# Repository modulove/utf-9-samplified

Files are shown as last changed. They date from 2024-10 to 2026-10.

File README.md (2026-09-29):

# UTF-9-samplified Drum Computer  

This project is based on the [bleep drum](https://bleeplabs.com/product/the-bleep-drum/) design by Dr. Bleep.

In 2025, **Felix Wiegeand (wgdmodular)** picked it up and released this **utf-9-samplified drum machine clone** with nice upgrades that make it perfect for starters and pros.

We (Modulove) put these into the hands of **beginners at DIY synthesizer solder workshops in 2025**.

- Few dozens were built.
- Every single one worked :)
- All were **hand-soldered by beginners (even kids!)**.

It turned out to be a **perfect entry-level project**.

The new firmware adds **Additonal functionality, fixes, and performance tricks** that came out of those builds and feedback from users.

---

## Firmware Updates

**Stable firmware (recommended):** 
Fixes the **button confusion issue**, fixed bad button behavior, small optimizations.
[https://dl.modulove.de/module/utf9/](https://dl.modulove.de/module/utf9/)

**Beta firmware (optional):**
Adds the new features: save/load slots, MIDI-to-CV clock, and more.
[https://dl.modulove.de/module/utf9/beta.html](https://dl.modulove.de/module/utf9/beta.html) 

Flash tool & instructions: [https://dl.modulove.de/module/utf9/](https://dl.modulove.de/module/utf9/)

---

## Supported boards

The firmware builds from a single sketch for three targets:

| Board | Notes |
|---|---|
| Arduino Nano | ATmega328P, new bootloader (115200 baud) |
| Arduino Nano (Old Bootloader) | ATmega328P, 57600 baud |
| LGT8F328P | Nano clone, built at `clock_div=2` so the chip runs at 16 MHz |

The LGT8F328P is an AVR-compatible clone whose internal RC oscillator runs at
32 MHz. The build divides it to 16 MHz so every timing in the sketch matches
the Nano, and the sample clock is derived from `F_CPU` rather than hardcoded,
so it lands on 9803.9 Hz on both. The LGT8F has no real EEPROM - the core
emulates it in flash, where writing one byte erases and rewrites a 1 KB page -
so pattern saves are staged and written as a single burst there.

None of this costs the Nano anything: the ATmega builds are byte-for-byte the
same size as before the dual-platform change.

**The Standard drumkit is Nano-only.** The LGT8F bootloader reserves 3 KB,
leaving 29696 bytes against the Nano's 30720, and Standard's sample set builds
to 30658. The other five kits all fit.

---

## Documentation

Docs of the **new features** here:

[docs/README.md](./docs/README.md)

The BOM is the docs/ folder as well.
[docs/BOM.md](./docs/BOM.md)

Find the ibom here:
[https://dl.modulove.de/module/utf9/ibom.html](https://dl.modulove.de/module/utf9/ibom.html)

---

## Links

The original Bleep Drum 
[https://bleeplabs.com/product/the-bleep-drum/](https://bleeplabs.com/product/the-bleep-drum/).

Old Bleep Drum User Guide & Hacking Info
[https://bleeplabs.com/bleep-drum-user-guide/](https://bleeplabs.com/bleep-drum-user-guide/).

---

## 💜 Thank You

Thanks for building with us
and huge thank yoouu to Felix from WGD Modular & John-Mike Reed aka Dr. Bleep who has been designing the initial Bleep Drum.

Linus & the Modulove workshop team

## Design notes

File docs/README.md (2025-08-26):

# UTF-9 Drum Computer — Enhanced Features & Documentation  

The features of the new UTF-9 drum computer firmware

---

## Improvements in this Firmware  (code)

- **Data type optimization** → leaner and faster code  
- **Simplified structure** → easier to read & hack  
- **Save/Load system** → intuitive and live-ready  

---

## Save / Load System  

```
SHIFT + [1-4]          → LOAD pattern from slot
SHIFT + REC + [1-4]    → SAVE pattern to slot
```

---

## Complete Control Summary  

| Action | Keys |
|---|---|
| **Trigger sounds** | Buttons 1-4 |
| **Load pattern** | SHIFT + Button 1-4 |
| **Save pattern** | SHIFT + REC → Button 1-4 |
| **Reverse mode** | SHIFT + PLAY |
| **MIDI channel select (on boot)** | Hold binary button combo |

---

## MIDI Channel Selection  

On boot, hold button combos to select MIDI channel **1–16**.  
Channel is saved to **EEPROM** and remembered!  

---

## MIDI Clock → Modular Converter  

```
Sequencer Playing → Pin 12 = Internal Clock
Sequencer Stopped → Pin 12 = MIDI Clock passthrough
```

So your drum computer doubles as a **MIDI-to-CV clock bridge** when idle!  

### Config Options (in code top)  
```cpp
#define MIDI_CLOCK_DIVIDER 6  // Clock division
#define MIDI_AUTO_START 0     // Auto start/stop with MIDI
```

- Clock divisions:  
  ```
  1  = 24 ppqn (fastest)
  2  = 12 ppqn
  4  =  6 ppqn (16ths)
  6  =  4 ppqn (8ths) [default]
  12 =  2 ppqn (quarters)
  24 =  1 ppqn (halves)
  48 =  0.5 ppqn (wholes)
  ```

- Auto Start:  
  ```
  0xFA → Start
  0xFC → Stop
  0xFB → Continue
  ```

---

## Key Features  

✔️ 4-Track step sequencer  
✔️ Reverse mode
✔️ MIDI channel select via buttons on boot
✔️ Modular-ready clock output  (TRS-Midi input)
✔️ Clock generator
✔️ **Proven beginner-friendly DIY hardware** 

---

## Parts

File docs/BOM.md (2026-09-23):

### utf-9-samplified BOM

| Designator | Footprint | Quantity  | Value |
|---|---|---|---|
| SW1,SW4,SW2,SW6,SW5,SW8,SW7,SW3 | SW_PUSH-12mm | 8 | 12x12 Tactile |
| R2,R1,R6,R5 | R_Axial_DIN0207_L6.3mm_D2.5mm_P7.62mm_Horizontal  | 4 | 1K |
| J2 | PJ301M-12 | 1 | PJ301M-12 |
| J3,J1 | Stereo PJ301M-12 | 2 | Stereo PJ301M-12  |
| D2 | LED_D5.0mm | 1 | LED |
| RV2,RV1 | Potentiometer_Alpha_RD901F-40-00D_Single_Vertical | 2 | B100K |
| U2 | DIP-8_W7.62mm | 1 | 6N137 |
| D1 | D_DO-35_SOD27_P7.62mm_Horizontal | 1 | 1N4148 |
| U1 | DIP-8_W7.62mm | 1 | MCP4901 |
| JP1 | TestPoint_2Pads_Pitch2.54mm_Drill0.8mm | 1 | Jumper |
| A1 | Arduino_Nano | 1 | Arduino_Nano_v3.x |
| A1 | Low profile pin-header | 2 | 3.5mm |

Make sure to flash the Arduino first and then solder it in directly or using low profile pin header! - otherwise it will be too high and the frontpanel wont fit.

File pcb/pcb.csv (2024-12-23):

Id | Designator | Footprint | Quantity | Designation | Supplier and ref
1 | SW1,SW4,SW2,SW6,SW5,SW8,SW7,SW3 | SW_PUSH-12mm | 8 | 12x12 Tactile
2 | R2,R1,R6,R5 | R_Axial_DIN0207_L6.3mm_D2.5mm_P7.62mm_Horizontal | 4 | 1K
3 | R3 | R_Axial_DIN0207_L6.3mm_D2.5mm_P7.62mm_Horizontal | 1 | 10K
4 | J3,J1,J2 | PJ301M-12 | 3 | PJ301M-12
5 | D2 | LED_D5.0mm | 1 | LED
6 | RV2,RV1 | Potentiometer_Alpha_RD901F-40-00D_Single_Vertical | 2 | B100K
7 | U2 | DIP-8_W7.62mm | 1 | 6N137
8 | D1 | D_DO-35_SOD27_P7.62mm_Horizontal | 1 | 1N4148
9 | R4 | R_Axial_DIN0207_L6.3mm_D2.5mm_P7.62mm_Horizontal | 1 | 220R
10 | U1 | DIP-8_W7.62mm | 1 | MCP4901
11 | C1 | CP_Radial_D5.0mm_P2.50mm | 1 | 10u
12 | JP1 | TestPoint_2Pads_Pitch2.54mm_Drill0.8mm | 1 | Jumper
13 | A1 | Arduino_Nano | 1 | Arduino_Nano_v3.x

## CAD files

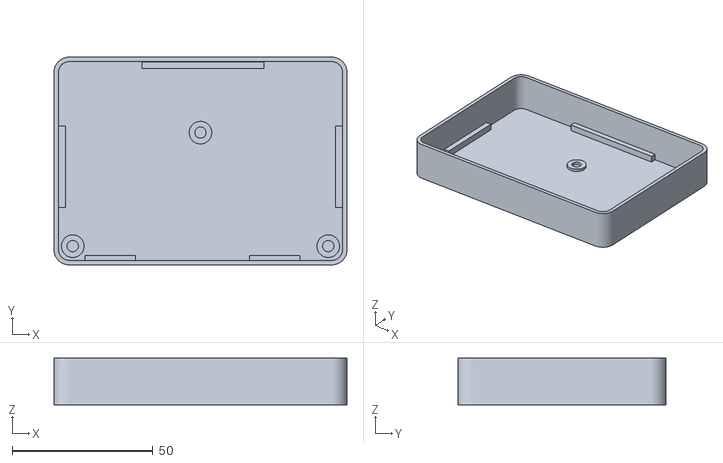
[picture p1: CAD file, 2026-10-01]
case/uft-9-samplified_case.stl
104.2 x 73.9 x 16.6

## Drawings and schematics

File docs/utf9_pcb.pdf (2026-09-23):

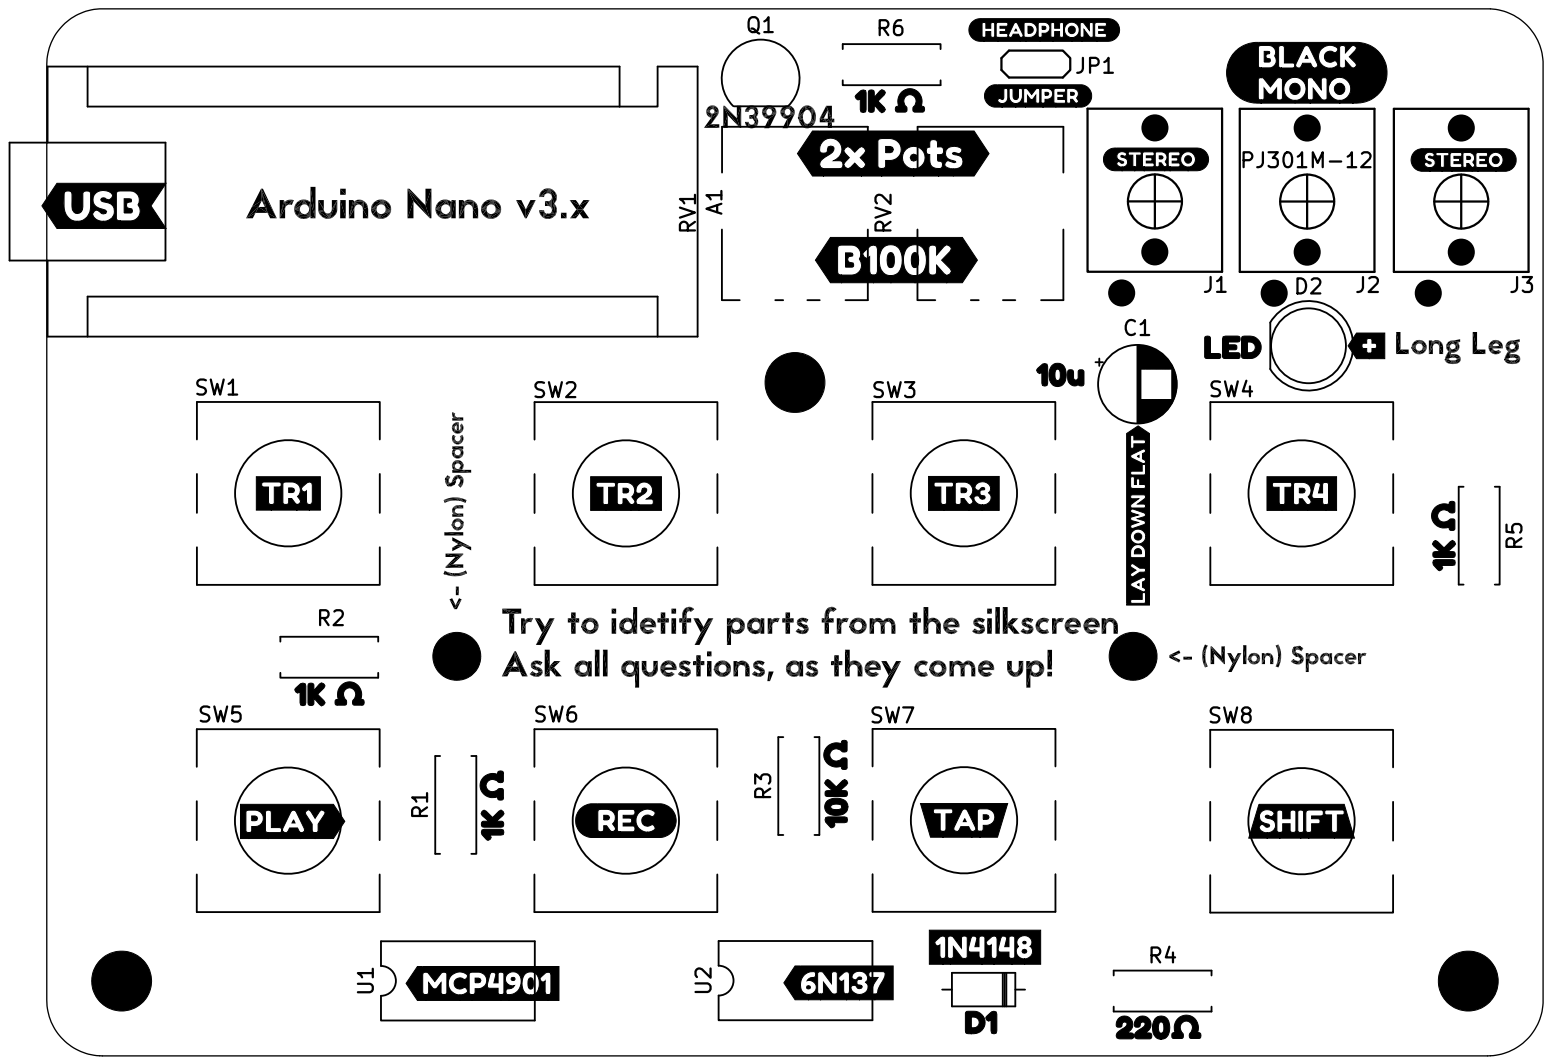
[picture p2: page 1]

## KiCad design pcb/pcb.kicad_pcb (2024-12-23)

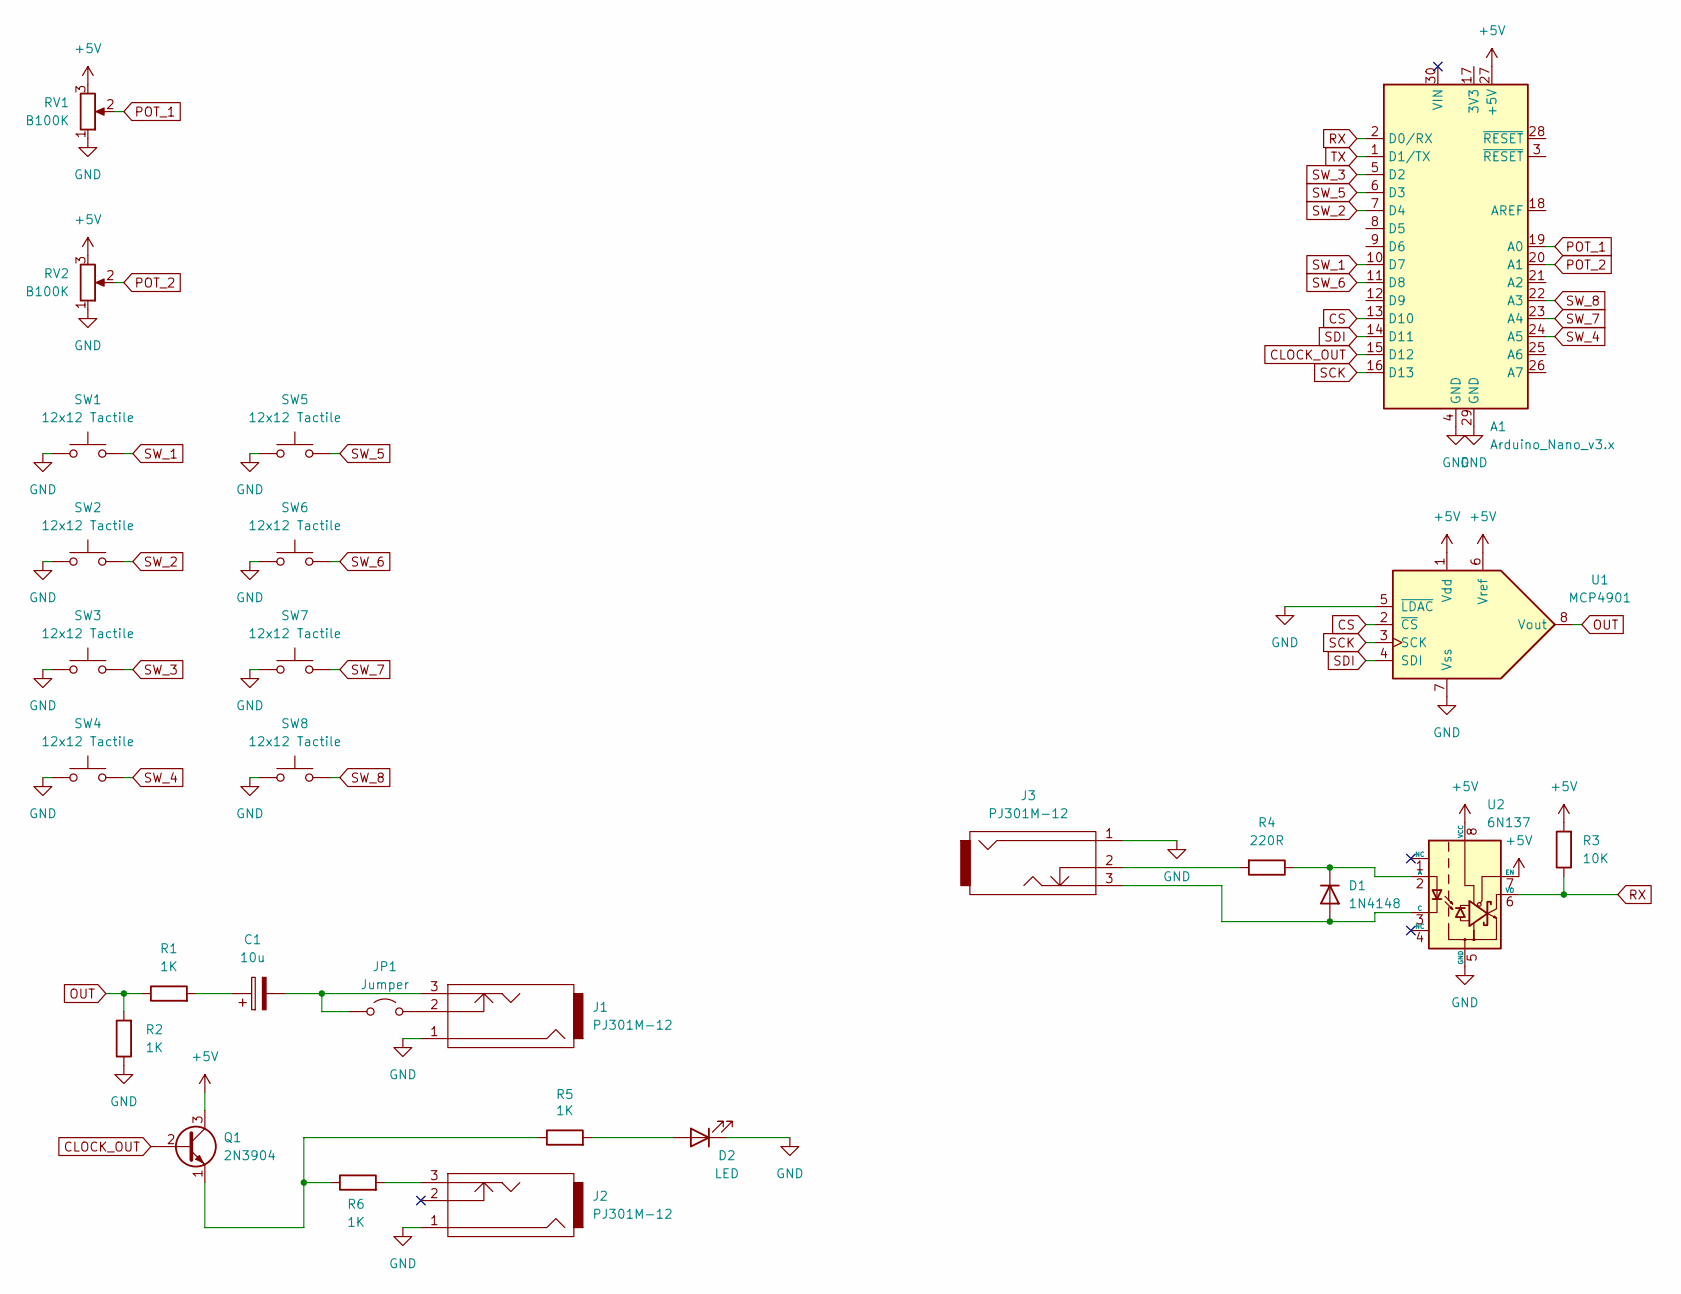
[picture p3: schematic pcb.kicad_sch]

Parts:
A1: Arduino_Nano_v3.x; Arduino_Nano
C1: 10u; CP_Radial_D5.0mm_P2.50mm
D1: 1N4148; D_DO-35_SOD27_P7.62mm_Horizontal
D2: LED; LED_D5.0mm
J1, J2, J3: PJ301M-12
JP1: Jumper; TestPoint_2Pads_Pitch2.54mm_Drill0.8mm
Q1: 2N3904; TO-92_Inline
R1, R2, R5, R6: 1K; R_Axial_DIN0207_L6.3mm_D2.5mm_P7.62mm_Horizontal
R3: 10K; R_Axial_DIN0207_L6.3mm_D2.5mm_P7.62mm_Horizontal
R4: 220R; R_Axial_DIN0207_L6.3mm_D2.5mm_P7.62mm_Horizontal
RV1, RV2: B100K; Potentiometer_Alpha_RD901F-40-00D_Single_Vertical
SW1, SW2, SW3, SW4, SW5, SW6, SW7, SW8: 12x12 Tactile; SW_PUSH-12mm
U1: MCP4901; DIP-8_W7.62mm
U2: 6N137; DIP-8_W7.62mm

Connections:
+5V: A1.27 (+5V), Q1.3 (C), R3.2, RV1.3, RV2.3, U1.1 (Vdd), U1.6 (Vref), U2.7 (EN), U2.8 (VCC)
CLOCK_OUT: A1.15 (D12), Q1.2 (B)
CS: A1.13 (D10), U1.2 (~CS)
GND: A1.4 (GND), A1.29 (GND), D2.1 (K), J1.1, J2.1, J3.1, R2.1, RV1.1, RV2.1, SW1.1, SW2.1, SW3.1, SW4.1, SW5.1, SW6.1, SW7.1, SW8.1, U1.5 (~LDAC), U1.7 (Vss), U2.5 (GND)
unnamed: C1.1, R1.2
unnamed: D1.2 (A), J3.3, U2.3 (C)
unnamed: D1.1 (K), R4.1, U2.2 (A)
unnamed: D2.2 (A), R5.2
unnamed: J2.3, R6.2
unnamed: J3.2, R4.2
unnamed: C1.2, J1.3, JP1.1 (A)
unnamed: J1.2, JP1.2 (B)
unnamed: Q1.1 (E), R5.1, R6.1
OUT: R1.1, R2.2, U1.8 (Vout)
POT_1: A1.19 (A0), RV1.2
POT_2: A1.20 (A1), RV2.2
RX: A1.2 (D0/RX), R3.1, U2.6 (VO)
SCK: A1.16 (D13), U1.3 (SCK)
SDI: A1.14 (D11), U1.4 (SDI)
SW_1: A1.10 (D7), SW1.2
SW_2: A1.7 (D4), SW2.2
SW_3: A1.5 (D2), SW3.2
SW_4: A1.24 (A5), SW4.2
SW_5: A1.6 (D3), SW5.2
SW_6: A1.11 (D8), SW6.2
SW_7: A1.23 (A4), SW7.2
SW_8: A1.22 (A3), SW8.2
TX: A1.1 (D1/TX)

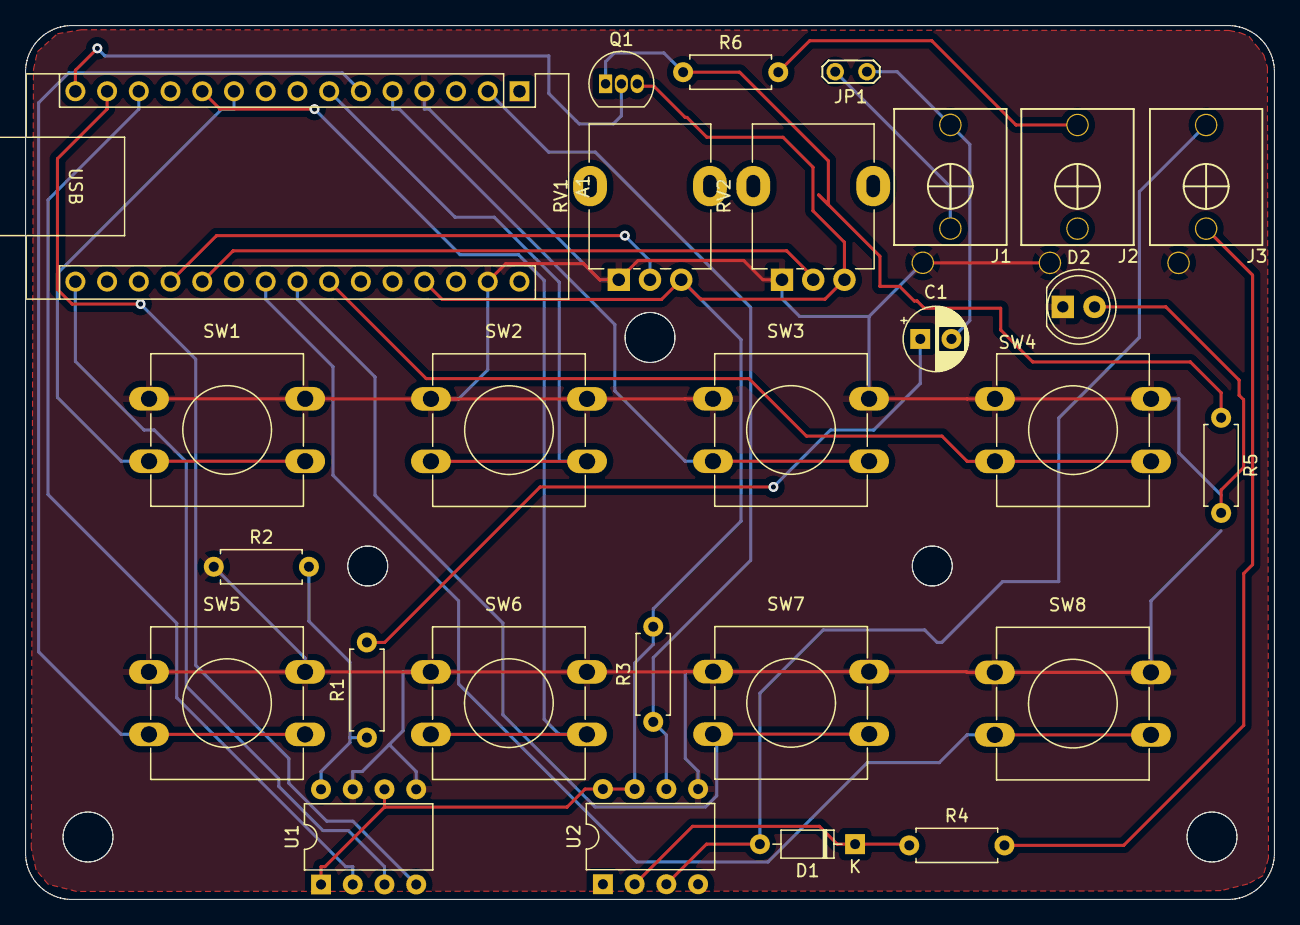
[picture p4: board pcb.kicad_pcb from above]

Board: 2 copper layers, 100.0 x 70.0 mm, 27 parts (0 on the bottom side), 27 nets.

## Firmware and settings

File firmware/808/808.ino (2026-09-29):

/*
   Original: The Bleep Drum
   By John-Mike Reed aka Dr. Bleep
   https://bleeplabs.com/product/the-bleep-drum/

   Updated version for 2025 WGD Modular UTF-9 rerelease
   OPTIMIZED VERSION with EEPROM Save/Load
   
   == MIDI CLOCK TO MODULAR ==
   The clock output (pin 12) has dual functionality:
   - When playing (play=1): Outputs internal sequencer clock
   - When stopped (play=0): Converts incoming MIDI clock to modular clock
   
   This allows the Bleep Drum to act as a MIDI-to-CV clock converter
   when not running its internal sequencer. Perfect for syncing
   your modular system to a DAW or other MIDI clock source.
   
   Clock divider can be set in code (MIDI_CLOCK_DIVIDER):
   - 1 = 24ppqn (every MIDI clock tick)
   - 2 = 12ppqn (every 2nd tick) 
   - 3 = 8th note triplets (8ppqn)
   - 4 = 16th notes (6ppqn)
   - 6 = 8th notes (4ppqn) [DEFAULT]
   - 8 = 8th note dots (3ppqn)
   - 12 = Quarter notes (2ppqn)
   - 24 = Half notes (1ppqn)
   - 48 = Whole notes (0.5ppqn)
   
   MIDI Start/Stop can optionally control sequencer:
   Set MIDI_AUTO_START to 1 in code to enable auto start/stop
   
   == MIDI CHANNEL SELECTION (on boot) ==
   Hold buttons during power-on to select MIDI channel:
   No buttons = Channel 1
   Button 1 = Channel 2
   Button 2 = Channel 3
   Button 1+2 = Channel 4
   Button 3 = Channel 5
   Button 1+3 = Channel 6
   Button 2+3 = Channel 7
   Button 1+2+3 = Channel 8
   Button 4 = Channel 9
   Button 1+4 = Channel 10
   Button 2+4 = Channel 11
   Button 1+2+4 = Channel 12
   Button 3+4 = Channel 13
   Button 1+3+4 = Channel 14
   Button 2+3+4 = Channel 15
   Button 1+2+3+4 = Channel 16
   LED flashes indicate selected channel
   
   == CONTROLS ==
   Buttons 1-4: Trigger sounds (when SHIFT not held)
   SHIFT + Button 1-4: Load pattern from slot 1-4 into current bank
   SHIFT + REC then Button 1-4: Save current bank to slot 1-4
   SHIFT + TAP + Button 1-4: Switch to bank 1-4
   SHIFT + TAP (hold): Adjust tempo with pot
   SHIFT + PLAY: Toggle reverse mode
   SHIFT + TAP (long hold): Toggle metronome on/off
   
   == SAVE/LOAD SYSTEM ==
   - Each slot stores ONE 32-step pattern
   - Save the current bank's pattern to any slot
   - Load any slot into the current bank
   - Build tracks by saving variations across slots
   - Metronome always OFF in saved patterns
   - Global tempo (not saved per pattern)
   - Auto-loads last saved slot on boot
   
   == WORKFLOW EXAMPLE ==
   1. Create beat in Bank 1, save to Slot 1
   2. Modify it, save variation to Slot 2
   3. Switch to Bank 2, load Slot 1, modify, save to Slot 3
   4. Live: Load slots 1-4 into any bank as needed
   
   == MIDI ==
   Notes 60, 62, 64, 65: Trigger sounds
   Notes 72, 74, 76, 77: Select banks 1-4
   Note 67: Play/Stop
   Note 69: Toggle reverse
   Note 70: Toggle noise mode
   CC 70-73: Control parameters
   MIDI Clock: Converted to modular clock when stopped
*/

#include <MIDI.h>
#include <EEPROM.h>
MIDI_CREATE_DEFAULT_INSTANCE();
#include <avr/pgmspace.h>
#include "samples.h"
#include <SPI.h>
#include <Bounce2.h>

// EEPROM Memory Map (1024 bytes total)
// Bytes 0-1:   Magic number (0xBE25)
// Bytes 2-15:  Settings:
//   Byte 2: Last saved slot (0-3)
//   Byte 3: Settings byte (play, click_en, playmode, noise_mode)
//   Byte 4: Current bank (0, 31, 63, or 95)
//   Byte 5: MIDI channel (1-16)
//   Bytes 6-15: Reserved for future use
// Bytes 16-271:  Save Slot 1 - One 32-step pattern
// Bytes 272-527: Save Slot 2 - One 32-step pattern
// Bytes 528-783: Save Slot 3 - One 32-step pattern
// Bytes 784-1023: Save Slot 4 - One 32-step pattern
//
// Each slot stores one 32-step pattern:
// - 16 bytes: Packed sequences (32 steps × 4 sequences, 2 steps per byte)
// - 32 bytes: B1 frequency values (compressed from int to byte)
// - 32 bytes: B2 frequency values (compressed from int to byte)
// - 176 bytes: Reserved for future expansion

#define EEPROM_MAGIC 0xBE25  // 2 bytes
#define EEPROM_SETTINGS_ADDR 2  // Start of settings (uses bytes 2-15)
#define EEPROM_BANK_START 16    // Start of bank storage
#define EEPROM_BANK_SIZE 256    // 256 bytes per save slot (4 slots total)

// Buttons
#define BTN1_PIN 4
#define BTN2_PIN 2
#define BTN3_PIN 7
#define BTN4_PIN 19

Bounce debouncerRed = Bounce();
Bounce debouncerGreen = Bounce();
Bounce debouncerBlue = Bounce();
Bounce debouncerYellow = Bounce();

// Control pins
#define play_pin  3
#define rec_pin   8
#define tap_pin   18
#define shift_pin 17

// MIDI Clock Settings
#define MIDI_CLOCK_DIVIDER 6    // 24 PPQN to 4 PPQN (6:1 ratio)
#define MIDI_AUTO_START 1       // 1=Auto start/stop with MIDI, 0=Manual only

uint32_t cm;
// ---------------------------------------------------------------------------
// Dual platform: ATmega328P at 16 MHz and LGT8F328P at 32 MHz, one sketch.
//
// The only thing that really has to change is the sample clock.  OCR2A was
// hardcoded to 50, which is 9803.9 Hz only at 16 MHz - on a 32 MHz LGT8F the
// same value runs the ISR at 19.6 kHz, so every sample plays an octave up and
// the sequencer runs at double tempo.  Deriving it from F_CPU gives 50 on the
// ATmega and 101 on the LGT8F, and the same 9803.9 Hz on both, which also
// keeps dds_tune below correct.
//
// The other difference is EEPROM: an LGT8F has none, and the core emulates it
// in flash by page swapping where a single byte written erases and rewrites a
// 1 KB page.  See eepromClearSlots() and saveToSlot().
#if defined(__LGT8FX8P__)
  #define IS_LGT8F 1
#else
  #define IS_LGT8F 0
#endif

#define DDS_HZ    9804UL
// Rounded, not truncated: F_CPU/32/DDS_HZ alone gives 50 at 16 MHz where the
// original used 51 ticks, and the two platforms then land on different rates
// (10000 Hz vs 9901 Hz) - which is the whole thing this is meant to avoid.
#define OCR2A_VAL ((uint8_t)(((F_CPU / 32UL + DDS_HZ / 2) / DDS_HZ) - 1))

const unsigned long dds_tune = 4294967296 / 9800;  // 2^32 / measured dds freq

// Optimized variables - keeping audio-critical ones as int
int sample_holder1;  // Keep as int for audio quality
uint16_t eee;
byte erase_latch, shift, banko = 0;
uint16_t pot1, pot2, pot3 = 200, pot4 = 200;
int8_t kick_sample, snare_sample, hat_sample, noise_sample, bass_sample;
int8_t B2_freq_sample, B1_freq_sample;
uint32_t accumulator, accumulator2, accumulator3, accumulator4, accumulator5;
uint32_t accu_freq_1, accu_freq_2;

// Sequences - keep original size for patterns
byte B2_sequence[128];
byte B3_sequence[128];
byte B1_sequence[128];
byte B4_sequence[128];
int B2_freq_sequence[128];  // KEEP AS INT for audio quality
int B1_freq_sequence[128];  // KEEP AS INT for audio quality

int kf, pf, kfe;  // KEEP AS INT for proper frequency
uint16_t index, index2, index3, index4, index5;
uint16_t index_freq_1, index_freq_2;
uint16_t indexr, index2r, index3r, index4r, index2vr, index4vr;
byte noise_mode = 1;
byte loopstep = 0, loopstepf = 0;
byte recordbutton, prevrecordbutton, record, prevloopstep;
byte revbutton, prevrevbutton;
uint32_t prev;
byte playmode = 1, play = 0;
byte playbutton, pplaybutton;
byte B4_trigger, B4_latch, B4_loop_trigger, B1_trigger, B1_latch;
byte B1_loop_trigger, B4_seq_trigger, B3_seq_trigger;
byte B1_seq_trigger, B3_latch, B2_trigger, B2_loop_trigger, B3_loop_trigger;
byte B2_latch, B3_trigger, B2_seq_trigger;
byte B2_seq_latch, B1_seq_latch, precordbutton;
byte recordmode = 1;
byte tapbutton, ptapbutton;
uint16_t taptempo = 1000;
uint16_t ratepot;
byte trigger_out_latch;
byte button1, button2, button3, button4, tapb;
byte pbutton1, pbutton2, pbutton3, pbutton4, ptapb;
byte tiggertempo, midistep, pmidistep, miditempo;
byte bf1, bf2, bf3, bf4, bft;
uint16_t midicc3 = 128, midicc4 = 157;
uint16_t midicc1, midicc2;
byte midi_note_check;
byte prevshift, shift_latch;
byte t;
uint16_t tapbank[2];  // Reduced from 4 to 2
uint16_t recordoffsettimer, offsetamount, taptempof;
int click_pitch;  // Use int for proper pitch values
byte click_amp, click_wait;
int sample_out_temp;  // Keep as int for proper audio mixing
byte sample_out;
uint32_t dds_time;
byte bft_latch;
uint16_t raw1, raw2;
uint32_t log1, log2;
byte click_play, click_en = 1;
uint16_t shift_time;
byte shift_time_latch;

// MIDI Clock to Modular Clock Configuration
// MIDI sends 24 clocks per quarter note (24ppqn)
// Change this value to set clock division when sequencer is stopped:
// 1 = 24ppqn (every tick), 3 = 8ppqn (triplets), 6 = 4ppqn (8th notes)
// 12 = 2ppqn (quarter notes), 24 = 1ppqn (half notes), etc.
#define MIDI_CLOCK_DIVIDER 6  // Default: 8th notes (4 pulses per quarter note)

// Set to 1 to enable auto start/stop with MIDI Start/Stop messages
#define MIDI_AUTO_START 0  // 0=disabled, 1=enabled

// Save/Load
byte save_mode = 0;  // 0=off, 1=waiting for button
byte last_saved_slot = 0;  // Remember which slot was last saved
byte midi_channel = 1;  // MIDI channel 1-16

// MIDI Clock to Modular Clock
byte midi_clock_counter = 0;
uint32_t midi_clock_out_time = 0;
byte midi_clock_out_latch = 0;

// Function declarations
void handleSaveLoad();
void saveToSlot(byte slot);
void loadFromSlot(byte slot);
void saveSettings();
void loadSettings();
byte checkEEPROM();
void flashConfirm();
byte midi_note_on();
void BUTTONS();
void RECORD();

// ISR variables
int8_t sine_sample;  // Declare here
byte index_sine;
uint32_t acc_sine;
uint32_t trig_out_time, prevtap;

void setup() {
  // No cli() here.  delay() and millis() are driven by Timer0's overflow
  // interrupt, so holding interrupts off across the boot delays below stops
  // them working - on a 16 MHz ATmega they limp, at 32 MHz they return early.
  // Interrupts are turned off again around the timer setup further down, which
  // is the only part that actually needs it.

  // Outputs
  pinMode(12, OUTPUT);
  pinMode(13, OUTPUT);
  pinMode(11, OUTPUT);
  pinMode(10, OUTPUT);
  pinMode(16, OUTPUT);
  digitalWrite(16, HIGH);

  // Inputs with pull-ups
  pinMode(play_pin, INPUT_PULLUP);
  pinMode(rec_pin, INPUT_PULLUP);
  pinMode(tap_pin, INPUT_PULLUP);
  pinMode(shift_pin, INPUT_PULLUP);
  pinMode(BTN1_PIN, INPUT_PULLUP);
  pinMode(BTN2_PIN, INPUT_PULLUP);
  pinMode(BTN3_PIN, INPUT_PULLUP);
  pinMode(BTN4_PIN, INPUT_PULLUP);

  debouncerGreen.attach(BTN3_PIN);
  debouncerGreen.interval(2);
  debouncerYellow.attach(BTN4_PIN);
  debouncerYellow.interval(2);
  debouncerBlue.attach(BTN2_PIN);
  debouncerBlue.interval(2);
  debouncerRed.attach(BTN1_PIN);
  debouncerRed.interval(2);

  delay(100);
  
  // MIDI Channel Selection on boot
  // Hold buttons during power-on to select MIDI channel 1-16
  // Binary encoding using 4 buttons: BTN1=1, BTN2=2, BTN3=4, BTN4=8
  // Channel = sum of pressed buttons + 1 (0 = channel 1, 15 = channel 16)
  
  midi_channel = 1;  // Default if no buttons pressed and no EEPROM data
  byte channel_select = 0;
  byte any_button_pressed = 0;
  
  if (digitalRead(BTN1_PIN) == 0) { channel_select += 1; any_button_pressed = 1; }
  if (digitalRead(BTN2_PIN) == 0) { channel_select += 2; any_button_pressed = 1; }
  if (digitalRead(BTN3_PIN) == 0) { channel_select += 4; any_button_pressed = 1; }
  if (digitalRead(BTN4_PIN) == 0) { channel_select += 8; any_button_pressed = 1; }
  
  // If buttons were pressed, set new channel
  if (any_button_pressed) {
    midi_channel = channel_select + 1;  // MIDI channels are 1-16, not 0-15
    
    // Visual feedback for channel selection
    // Quick flash = tens digit, slow flashes = ones digit
    if (midi_channel >= 10) {
      digitalWrite(13, HIGH);
      delay(300);
      digitalWrite(13, LOW);
      delay(200);
    }
    
    byte ones = midi_channel % 10;
    if (ones == 0) ones = 10;  // Show 10 flashes for 10
    
    for (byte i = 0; i < ones; i++) {
      digitalWrite(13, HIGH);
      delay(100);
      digitalWrite(13, LOW);
      delay(100);
    }
    delay(500);
  }
  // Otherwise midi_channel will be loaded from EEPROM later
  
  MIDI.begin(midi_channel);
  MIDI.turnThruOff();

  SPI.begin();
  SPI.setBitOrder(MSBFIRST);

  // Timer2 ISR
  cli();                       // only the timer setup needs interrupts off
  TIMSK2 = (1 << OCIE2A);
  OCR2A = OCR2A_VAL;
  TCCR2A = (1 << WGM21);
  TCCR2B = (1 << CS21) | (1 << CS20);
  TCCR0B = B0000001;
  TCCR1B = B0000001;

  sei();

  noise_mode = (digitalRead(shift_pin) == 0) ? 1 : 0;
  
  // Load saved data (including MIDI channel if not set by buttons)
  if (checkEEPROM()) {
    if (!any_button_pressed) {
      // No buttons pressed, load saved channel
      loadSettings();  // This loads banko position and MIDI channel
      // Re-initialize MIDI with loaded channel
      MIDI.begin(midi_channel);
      MIDI.turnThruOff();
    } else {
      // Buttons were pressed, keep the selected channel
      loadSettings();  // Load other settings
      // midi_channel already set from button presses
      saveSettings();  // Save the new channel selection
    }
    byte last_slot = EEPROM.read(EEPROM_SETTINGS_ADDR);
    if (last_slot < 4) {
      loadFromSlot(last_slot);  // Load last saved pattern into current bank
    }
  }
}
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
void loop() {
  cm = millis();
  
  midi_note_check = midi_note_on();

  pbutton1 = button1; pbutton2 = button2; pbutton3 = button3; pbutton4 = button4;

  debouncerRed.update();
  debouncerBlue.update();
  debouncerGreen.update();
  debouncerYellow.update();

  button1 = debouncerRed.read();
  button2 = debouncerBlue.read();
  button3 = debouncerGreen.read();
  button4 = debouncerYellow.read();

  tapb = digitalRead(tap_pin);

  bf1 = (button1 == 0 && pbutton1 == 1);
  bf2 = (button2 == 0 && pbutton2 == 1);
  bf3 = (button3 == 0 && pbutton3 == 1);
  bf4 = (button4 == 0 && pbutton4 == 1);

  if (tapb == 0 && ptapbutton == 1 && !bft_latch) { bft = 1; bft_latch = 1; }
  else { bft = 0; bft_latch = 0; }

  // MIDI controls
  if (midi_note_check == 67) {
    play = !play;
    midi_clock_counter = 0;  // Reset MIDI clock counter
    digitalWrite(12, LOW);
  }
  if (midi_note_check == 69) playmode = !playmode;
  if (midi_note_check == 70) { shift_latch = 1; noise_mode = !noise_mode; }
  
  // MIDI bank select (consistent with button mapping)
  if (midi_note_check == 72) banko = 0;   // Bank 1
  if (midi_note_check == 74) banko = 31;  // Bank 2
  if (midi_note_check == 76) banko = 63;  // Bank 3
  if (midi_note_check == 77) banko = 95;  // Bank 4

  ptapbutton = tapb;
  pmidistep = midistep;

  BUTTONS();
  RECORD();
  handleSaveLoad();

  // Read pots
  raw1 = analogRead(0);
  log1 = (uint32_t)raw1 * raw1;
  raw2 = analogRead(1);
  log2 = (uint32_t)raw2 * raw2;

  if (noise_mode == 0) {
    pot1 = (log1 >> 11) + 2;
    pot2 = (log2 >> 11) + 42;
  } else {
    if (shift_latch == 0) {
      pot1 = (log1 >> 11) + 1;
      pot2 = (log2 >> 12) + 1;
    } else {
      pot3 = (log1 >> 6) + 1;
      pot4 = (log2 >> 8) + 1;
    }
  }
}

void RECORD() {
  pplaybutton = playbutton;
  playbutton = digitalRead(play_pin);
  if (pplaybutton == 1 && playbutton == 0 && shift == 1 && recordbutton == 1) {
    play = !play;
    midi_clock_counter = 0;
    digitalWrite(12, LOW);
  }

  precordbutton = recordbutton;
  recordbutton = digitalRead(rec_pin);
  if (recordbutton == 0 && precordbutton == 1) {
    record = !record;
    play = 1;
    erase_latch = 1;
    eee = 0;
  }
  if (recordbutton == 1 && precordbutton == 0) {
    erase_latch = 0;
  }

  if (play == 0) record = 0;

  // Hold REC + PLAY to erase
  if (recordbutton == 0 && playbutton == 0 && erase_latch == 1) {
    if (++eee >= 800) {
      eee = 0;
      erase_latch = 0;
      play = 1;
      record = 0;
      for (byte j = 0; j < 32; j++) {
        B1_sequence[j + banko] = 0;
        B2_sequence[j + banko] = 0;
        B4_sequence[j + banko] = 0;
        B3_sequence[j + banko] = 0;
      }
    }
  }

  if (record == 1) {
    // FIX: Capture loopstepf atomically to prevent race condition
    byte record_step;
    cli();  // Disable interrupts
    record_step = loopstepf;
    sei();  // Re-enable interrupts
    
    // Now use the captured value consistently
    if (B1_trigger) {
      B1_sequence[record_step + banko] = 1;
      B1_freq_sequence[record_step + banko] = pot1;
    }
    if (B2_trigger) {
      B2_sequence[record_step + banko] = 1;
      B2_freq_sequence[record_step + banko] = pot2;
    }
    if (B4_trigger) B4_sequence[record_step + banko] = 1;
    if (B3_trigger) B3_sequence[record_step + banko] = 1;
  }
}

void BUTTONS() {
  prevshift = shift;
  shift = digitalRead(shift_pin);

  if (shift == 0 && prevshift == 1) {
    shift_latch = !shift_latch;
    shift_time = 0;
    shift_time_latch = 1;
  }

  if (shift == 0 && tapb == 1 && shift_time_latch == 1) {
    if (++shift_time > 800) {
      click_en = !click_en;
      shift_time = 0;
      shift_time_latch = 0;
    }
  }

  // Bank select with SHIFT + TAP + button (doesn't conflict with load)
  if (shift == 0 && tapb == 0 && recordbutton == 1) {
    if (button1 == 0) banko = 0;   // Bank 1
    if (button2 == 0) banko = 31;  // Bank 2 
    if (button3 == 0) banko = 63;  // Bank 3
    if (button4 == 0) banko = 95;  // Bank 4
  }

  // Tempo adjustment when holding SHIFT + TAP (no buttons)
  if (shift == 0 && tapb == 0 && recordbutton == 1) {
    play = 1;
    ratepot = analogRead(1);
    taptempo = ((ratepot - 1024) * -1) << 2;
  }

  // Reverse mode with SHIFT + PLAY
  if (shift == 0 && recordbutton == 1 && save_mode == 0) {
    revbutton = digitalRead(play_pin);
    if (revbutton == 0 && prevrevbutton == 1) playmode = !playmode;
    prevrevbutton = revbutton;
  }

  // Triggers (when not holding SHIFT, and not in save mode)
  if (shift == 1 && save_mode == 0) {
    B1_trigger = (bf1 || midi_note_check == 60);
    B4_trigger = (bf4 || midi_note_check == 65);
    B2_trigger = (bf2 || midi_note_check == 62);
    B3_trigger = (bf3 || midi_note_check == 64);
  } else {
    // Clear triggers when in save mode or holding shift
    B1_trigger = 0;
    B2_trigger = 0;
    B3_trigger = 0;
    B4_trigger = 0;
  }
}

void handleSaveLoad() {
  // SHIFT + REC = Enter save mode (saves current bank pattern)
  if (shift == 0 && recordbutton == 0 && playbutton == 1) {
    save_mode = 1;
    // Visual feedback - quick flash
    play = !play;
    delay(50);
    play = !play;
  }
  
  // Exit save mode if shift released
  if (shift == 1) {
    save_mode = 0;
  }
  
  // Direct load: SHIFT + Button (no PLAY needed)
  if (shift == 0 && recordbutton == 1 && playbutton == 1) {
    if (bf1) { loadFromSlot(0); flashConfirm(); }
    if (bf2) { loadFromSlot(1); flashConfirm(); }
    if (bf3) { loadFromSlot(2); flashConfirm(); }
    if (bf4) { loadFromSlot(3); flashConfirm(); }
  }
  
  // In save mode - wait for button 1-4 to save current pattern
  if (save_mode == 1) {
    if (bf1) { saveToSlot(0); save_mode = 0; flashConfirm(); }
    if (bf2) { saveToSlot(1); save_mode = 0; flashConfirm(); }
    if (bf3) { saveToSlot(2); save_mode = 0; flashConfirm(); }
    if (bf4) { saveToSlot(3); save_mode = 0; flashConfirm(); }
  }
}

void flashConfirm() {
  byte p = play;
  for (byte i = 0; i < 3; i++) {
    play = !play;
    delay(80);
  }
  play = p;
}

// A slot only ever holds 80 bytes: 16 packed step bytes then two 32-byte
// frequency lanes.  The original cleared all 1008 bytes from EEPROM_BANK_START
// to the top, which on an LGT8F is 1008 page erase-and-rewrites - several
// seconds of stall and about a tenth of the flash's endurance, every time the
// magic does not match.  And on an LGT8F the emulated EEPROM is wiped by every
// sketch upload, so that is every upload.
#define SLOT_BYTES 80
void eepromClearSlots() {
#if IS_LGT8F
  uint8_t zero[SLOT_BYTES];
  for (uint8_t i = 0; i < SLOT_BYTES; i++) zero[i] = 0;
  for (uint8_t sl = 0; sl < 4; sl++)
    lgt_eeprom_writeSWM(EEPROM_BANK_START + (uint16_t)sl * EEPROM_BANK_SIZE,
                        (uint32_t *)zero, SLOT_BYTES / 4);
#else
  for (uint16_t i = EEPROM_BANK_START; i < 1024; i++) EEPROM.update(i, 0);
#endif
}

void saveToSlot(byte slot) {
  if (slot > 3) return;
  
  uint16_t addr = EEPROM_BANK_START + (slot * EEPROM_BANK_SIZE);

  // On the LGT8F the 80 bytes are staged and written as one page burst.
  // On a real EEPROM they go straight out through update(), which already
  // skips unchanged bytes - staging there would cost 80 bytes of RAM and
  // ~100 of flash for no gain, and the standard kit has room for neither.
#if IS_LGT8F
  uint8_t buf[SLOT_BYTES];
  #define SLOT_PUT(i, v) buf[i] = (v)
#else
  #define SLOT_PUT(i, v) EEPROM.update(addr + (i), (v))
#endif
  
  // Save only the CURRENT 32-step pattern (based on banko)
  // Pack 2 steps into 1 byte (4 bits per step for 4 sequences)
  for (byte i = 0; i < 16; i++) {  // 16 bytes for 32 steps
    byte packed = 0;
    byte idx = (i * 2) + banko;  // Use banko offset to get current bank
    
    // Pack 2 steps into 1 byte
    if (B1_sequence[idx]) packed |= 0x01;
    if (B2_sequence[idx]) packed |= 0x02;
    if (B3_sequence[idx]) packed |= 0x04;
    if (B4_sequence[idx]) packed |= 0x08;
    if (B1_sequence[idx + 1]) packed |= 0x10;
    if (B2_sequence[idx + 1]) packed |= 0x20;
    if (B3_sequence[idx + 1]) packed |= 0x40;
    if (B4_sequence[idx + 1]) packed |= 0x80;
    
    SLOT_PUT(i, packed);
  }
  
  // Save B1 frequency sequences for current bank (32 values)
  for (byte i = 0; i < 32; i++) {
    SLOT_PUT(16 + i, constrain(B1_freq_sequence[i + banko] >> 2, 0, 255));
  }
  
  // Save B2 frequency sequences for current bank (32 values)
  for (byte i = 0; i < 32; i++) {
    SLOT_PUT(48 + i, constrain(B2_freq_sequence[i + banko] >> 2, 0, 255));
  }
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

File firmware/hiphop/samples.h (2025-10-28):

#ifndef SAMPLES_PACK4_H
#define SAMPLES_PACK4_H

#include <Arduino.h>
#include <avr/pgmspace.h>

const byte kick_table[] PROGMEM = {
  127, 127, 129, 133, 135, 137, 139, 140, 139, 131, 115, 104, 98, 94, 91, 88,
  86, 84, 83, 82, 81, 81, 81, 81, 82, 83, 85, 88, 92, 101, 119, 147,
  180, 204, 215, 220, 222, 222, 221, 219, 217, 214, 211, 208, 204, 201, 197, 193,
  188, 184, 178, 171, 159, 136, 103, 72, 54, 47, 43, 41, 41, 41, 42, 44,
  47, 50, 54, 58, 62, 69, 79, 93, 113, 133, 154, 173, 186, 193, 197, 199,
  199, 199, 198, 196, 194, 191, 188, 185, 180, 176, 169, 159, 142, 116, 89, 68,
  55, 49, 45, 43, 42, 43, 45, 47, 49, 52, 55, 58, 61, 65, 69, 73,
  77, 82, 87, 94, 104, 120, 142, 166, 187, 203, 213, 218, 220, 221, 220, 219,
  217, 214, 211, 208, 204, 201, 197, 193, 188, 183, 178, 173, 165, 153, 133, 109,
  85, 67, 54, 46, 41, 38, 38, 39, 40, 42, 44, 47, 50, 53, 57, 61,
  65, 69, 74, 80, 88, 99, 117, 138, 162, 183, 197, 206, 211, 213, 213, 213,
  211, 210, 208, 205, 202, 199, 196, 193, 189, 185, 182, 178, 174, 170, 165, 161,
  156, 150, 143, 131, 113, 91, 67, 48, 36, 29, 26, 25, 25, 26, 28, 30,
  34, 37, 40, 45, 48, 52, 56, 61, 65, 70, 74, 79, 84, 89, 96, 105,
  117, 135, 155, 174, 193, 207, 215, 220, 222, 223, 223, 221, 219, 217, 214, 211,
  208, 204, 200, 197, 192, 188, 184, 180, 176, 172, 168, 164, 159, 154, 148, 139,
  125, 106, 86, 66, 49, 38, 31, 27, 26, 26, 28, 30, 33, 35, 39, 42,
  45, 50, 54, 58, 61, 66, 70, 73, 77, 82, 86, 90, 95, 99, 103, 108,
  114, 123, 138, 158, 181, 203, 218, 228, 233, 235, 235, 234, 233, 230, 227, 224,
  220, 217, 213, 208, 204, 201, 196, 192, 187, 184, 180, 175, 171, 167, 162, 159,
  154, 150, 146, 141, 136, 130, 120, 105, 83, 61, 41, 27, 19, 16, 15, 16,
  18, 20, 23, 26, 30, 34, 38, 42, 46, 51, 55, 59, 63, 68, 72, 76,
  80, 84, 88, 92, 96, 100, 104, 108, 112, 116, 121, 127, 135, 147, 164, 185,
  207, 225, 237, 242, 245, 244, 243, 241, 238, 234, 231, 226, 223, 218, 214, 210,
  205, 200, 196, 192, 188, 183, 179, 175, 171, 167, 163, 158, 155, 151, 147, 143,
  139, 135, 131, 127, 122, 117, 109, 99, 86, 70, 54, 37, 23, 14, 10, 8,
  9, 11, 14, 17, 21, 25, 29, 34, 38, 43, 47, 51, 56, 60, 65, 69,
  73, 77, 81, 85, 89, 93, 97, 101, 104, 108, 112, 116, 119, 123, 127, 131,
  136, 142, 151, 163, 180, 198, 216, 232, 242, 247, 249, 249, 247, 245, 242, 238,
  234, 230, 225, 221, 216, 211, 207, 202, 198, 193, 189, 184, 180, 176, 172, 168,
  164, 160, 156, 152, 149, 145, 141, 137, 134, 130, 127, 123, 119, 115, 109, 104,
  95, 84, 71, 57, 42, 30, 20, 12, 8, 7, 8, 9, 12, 16, 19, 23,
  27, 31, 36, 40, 45, 49, 54, 59, 63, 67, 72, 76, 80, 84, 88, 92,
  95, 99, 102, 106, 110, 113, 117, 120, 123, 126, 129, 133, 135, 138, 141, 144,
  147, 151, 154, 160, 166, 175, 187, 201, 215, 229, 241, 249, 252, 252, 251, 248,
  245, 241, 237, 233, 229, 224, 219, 215, 210, 205, 200, 196, 191, 186, 182, 177,
  173, 169, 165, 161, 157, 153, 150, 146, 142, 139, 136, 132, 129, 126, 122, 119,
  116, 112, 109, 104, 100, 93, 86, 77, 66, 55, 43, 33, 23, 15, 9, 6,
  5, 6, 8, 10, 14, 18, 22, 26, 31, 35, 40, 45, 49, 54, 58, 63,
  67, 71, 76, 80, 84, 88, 92, 96, 99, 103, 107, 110, 113, 117, 119, 123,
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
};

uint16_t kick_length = 2138;

const byte snare_table[] PROGMEM = {
  127, 127, 126, 125, 140, 145, 131, 97, 93, 137, 156, 143, 106, 77, 121, 171,
  159, 125, 54, 60, 166, 203, 136, 42, 61, 109, 215, 227, 63, 53, 118, 237,
  207, 162, 80, 107, 112, 103, 99, 66, 30, 134, 223, 172, 39, 58, 107, 173,
  248, 193, 144, 149, 246, 212, 157, 108, 75, 58, 56, 64, 90, 91, 107, 177,
  137, 104, 51, 99, 157, 220, 252, 235, 231, 235, 201, 142, 91, 58, 42, 42,
  53, 97, 125, 118, 123, 118, 120, 119, 115, 141, 178, 199, 203, 200, 194, 176,
  147, 117, 95, 82, 79, 82, 93, 115, 122, 123, 128, 135, 137, 137, 139, 144,
  150, 151, 152, 152, 148, 141, 132, 122, 116, 112, 110, 112, 114, 118, 123, 126,
  130, 131, 132, 132, 134, 135, 136, 137, 137, 137, 136, 132, 129, 125, 122, 120,
  119, 119, 120, 122, 123, 125, 127, 128, 129, 129, 131, 131, 132, 132, 133, 132,
  131, 129, 127, 125, 123, 122, 121, 122, 122, 122, 123, 124, 125, 126, 127, 128,
  128, 129, 129, 129, 129, 129, 128, 127, 126, 125, 124, 123, 123, 123, 123, 123,
  123, 124, 124, 125, 126, 126, 127, 127, 127, 127, 127, 127, 126, 125, 125, 124,
  124, 123, 123, 123, 123, 123, 123, 124, 125, 125, 126, 126, 126, 126, 126, 126,
  126, 126, 126, 125, 125, 125, 124, 124, 124, 123, 123, 124, 124, 124, 124, 124,
  124, 125, 125, 125, 125, 125, 125, 125, 125, 124, 124, 124, 123, 123, 123, 124,
  124, 124, 124, 124, 125, 125, 125, 125, 125, 125, 125, 125, 125, 125, 125, 124,
  124, 124, 124, 124, 124, 124, 124, 124, 124, 124, 124, 124, 124, 124, 124, 124,
  125, 125, 125, 125, 125, 125, 125, 125, 125, 124, 124, 124, 124, 124, 124, 124,
  124, 124, 125, 125, 124, 124, 125, 125, 124, 124, 124, 124, 124, 124, 124, 124,
  124, 124, 124, 125, 125, 125, 125, 125, 125, 125, 125, 125, 125, 125, 125, 125,
  125, 125, 125, 125, 125, 125, 125, 125, 125, 125, 125, 125, 125, 125, 125, 125,
  125, 125, 125, 125, 125, 125, 125, 125, 125, 125, 125, 125, 125, 125, 125, 125,
  126, 126, 126, 126, 126, 126, 126, 126, 126, 126, 126, 126, 126, 126, 126, 126,
  126, 125, 125, 125, 126, 126, 126, 126, 126, 126, 126, 126, 126, 126, 126, 126,
  126, 126, 126, 126, 126, 126, 126, 126, 126, 126, 126, 126, 126, 126, 126, 126,
  126, 126, 126, 126, 126, 126, 126, 126, 126, 126, 126, 126, 126, 126, 126, 126,
  126, 126, 126, 126, 126, 126, 126, 126, 126, 126, 126, 126, 126, 126, 126, 126,
  126, 126, 126, 126, 126, 126, 126, 126, 126, 126, 126, 126, 126, 126, 127, 127,
  127, 127, 127, 127, 127, 127, 127, 127, 127, 127, 127, 127, 127, 127, 127, 127,
  127, 127, 127, 127, 127, 127, 127, 127, 127, 127, 127, 127, 127, 127
};

uint16_t snare_length = 493;
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

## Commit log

2024-10-20 Finish Rev 1
    [panel.kicad_pcb, pcb.kicad_pcb]
2024-12-23 Revert MIDI jack
    [pcb.csv, pcb.kicad_pcb, pcb.kicad_sch]
2024-12-23 Fix clock output
    [pcb.kicad_pcb, pcb.kicad_sch]
2025-03-08 Fix BOM
2025-08-18 Fix buttons in firmware.ino
    correct pull-ups, clean up a bit
2025-08-18 clean RGB led from firmware.ino
    No RGB Led in there
2025-08-22 Update README.md
    remove bs flowcharts etc
2025-08-25 Create BOM.md
    move BOM to docs/ folder
2025-08-25 Update README.md
    no bank switching for now
2025-10-28 Add GitHub Actions workflow for automated firmware builds
    - Build all 6 drumkit variants (standard, 808, 909, hiphop, industrial, experimental)
    - Compile for both Arduino Nano and Nano (Old Bootloader)
    - Generate .hex files for web-based flashing
    - Upload artifacts for each build
    - Automatic release creation on tags
    - Install required libraries: MIDI, Bounce2
    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
2025-10-28 Fix MIDI library installation name
    Changed from 'MIDI' to 'MIDI Library' (the correct Arduino Library Manager name)
    This resolves the build error:
    Error installing MIDI: Library 'MIDI' not found
2025-10-28 Fix board FQBN for old bootloader compilation
    Changed from 'nanoOldBootloader' to 'nano:cpu=atmega328old' which is the correct
    Arduino board variant identifier.
    Correct FQBNs:
    - New bootloader: arduino:avr:nano
    - Old bootloader: arduino:avr:nano:cpu=atmega328old
    Error during build: Invalid FQBN: board arduino:avr:nanoOldBootloader not found
    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
2026-09-23 Revise BOM
    Updated component list
2026-09-23 Add pcb printout sheet for workshops
    This can be used to lay out all components in a dry run before getting to work with placing & soldering.
2026-09-29 Add LGT8F328P support to firmware and build matrix
    The sketch now builds unchanged for the ATmega328P Nano and the LGT8F328P
    Nano clone. Two things differ between the chips and both are handled at
    compile time:
    - Sample clock. OCR2A was hardcoded to 50, which is 9803.9 Hz only at
    16 MHz. It is now derived from F_CPU, so it lands on the same 9803.9 Hz
    on either part and dds_tune stays correct.
    - EEPROM. The LGT8F has none; its core emulates it in flash, where writing
    a single byte erases and rewrites a 1 KB page. Pattern saves are staged
    and written as one burst there, and the startup clear touches only the
    320 bytes the four slots use instead of all 1008.
    The staging buffer is co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
    [808.ino, 909.ino, experimental.ino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]
2026-10-01 Add case
    This saves desks from getting scratched by solder blobs on the bottom of the device.
    Use rubber feets to make it stable. We like to make these from PETG
    [uft-9-samplified_case.stl]
